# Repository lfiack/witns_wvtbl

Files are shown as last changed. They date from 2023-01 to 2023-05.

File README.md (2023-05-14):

# witns_wvtbl
Wavetable oscillator

## Make the project work
This project uses a submodule for the KiCAD library. To get it properly, use the `--recursive` option when cloning the repo :
```
git clone --recursive git@github.com:lfiack/witns_wvtbl.git
```

The firmware is developped with VSCode and the `stm32-for-vscode` plugin. There is now a plugin developped by ST, but I didn't take time to test it.

## Where to download wavetables ?
* [Free Serum Wavetables](https://www.antidoteaudio.com/free-serum-wavetables)
* [Adventurekid](https://www.adventurekid.se/akrt/waveforms/)

## TODO
* Add -12V Label

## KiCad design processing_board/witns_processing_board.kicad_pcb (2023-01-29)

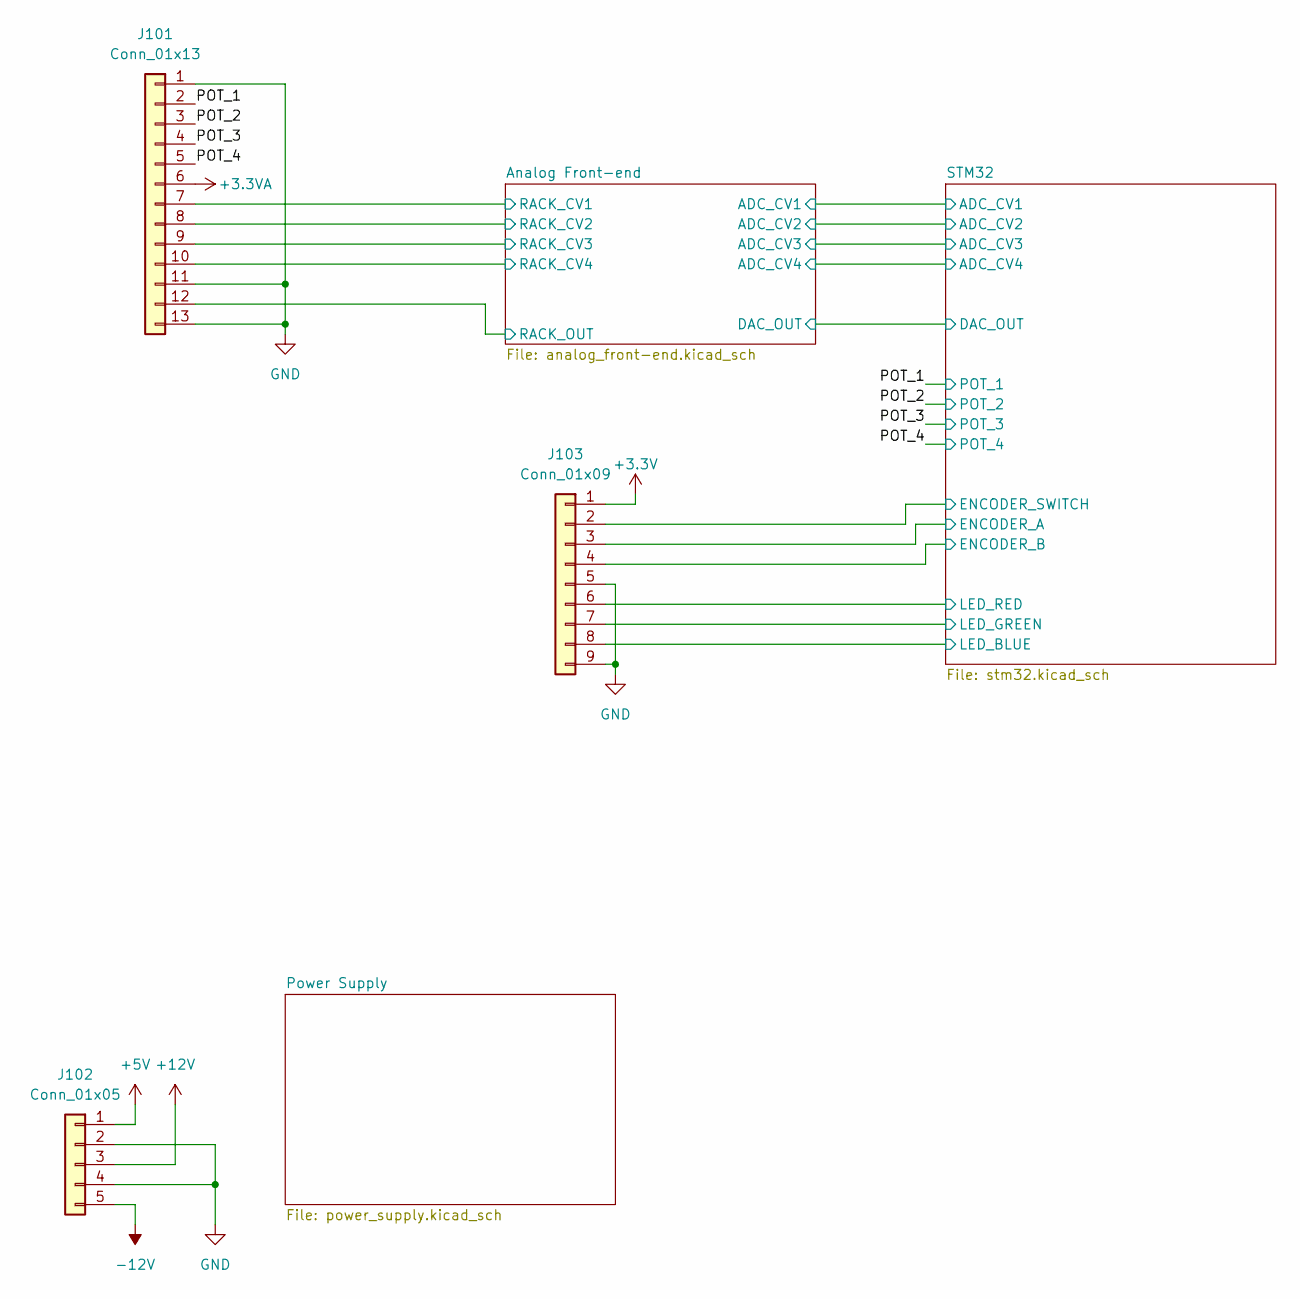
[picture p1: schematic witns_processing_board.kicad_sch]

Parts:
J101: Conn_01x13; PinHeader_1x13_P2.54mm_Vertical
J102: Conn_01x05; PinHeader_1x05_P2.54mm_Vertical
J103: Conn_01x09; PinHeader_1x09_P2.54mm_Vertical

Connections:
+3.3VA: J101.6; also elsewhere on the board
+3V3: J103.1; also elsewhere on the board
+5V: J102.1; also elsewhere on the board
+12V: J102.3; also elsewhere on the board
-12V: J102.5; also elsewhere on the board
/Analog Front-end/RACK_CV1: J101.7; also elsewhere on the board
/Analog Front-end/RACK_CV2: J101.8; also elsewhere on the board
/Analog Front-end/RACK_CV3: J101.9; also elsewhere on the board
/Analog Front-end/RACK_CV4: J101.10; also elsewhere on the board
/Analog Front-end/RACK_OUT: J101.12; also elsewhere on the board
/POT_1: J101.2; also elsewhere on the board
/POT_2: J101.3; also elsewhere on the board
/POT_3: J101.4; also elsewhere on the board
/POT_4: J101.5; also elsewhere on the board
/STM32/ENCODER_A: J103.3; also elsewhere on the board
/STM32/ENCODER_B: J103.4; also elsewhere on the board
/STM32/ENCODER_SWITCH: J103.2; also elsewhere on the board
/STM32/LED_BLUE: J103.8; also elsewhere on the board
/STM32/LED_GREEN: J103.7; also elsewhere on the board
/STM32/LED_RED: J103.6; also elsewhere on the board
GND: J101.1, J101.11, J101.13, J102.2, J102.4, J103.5, J103.9; also elsewhere on the board

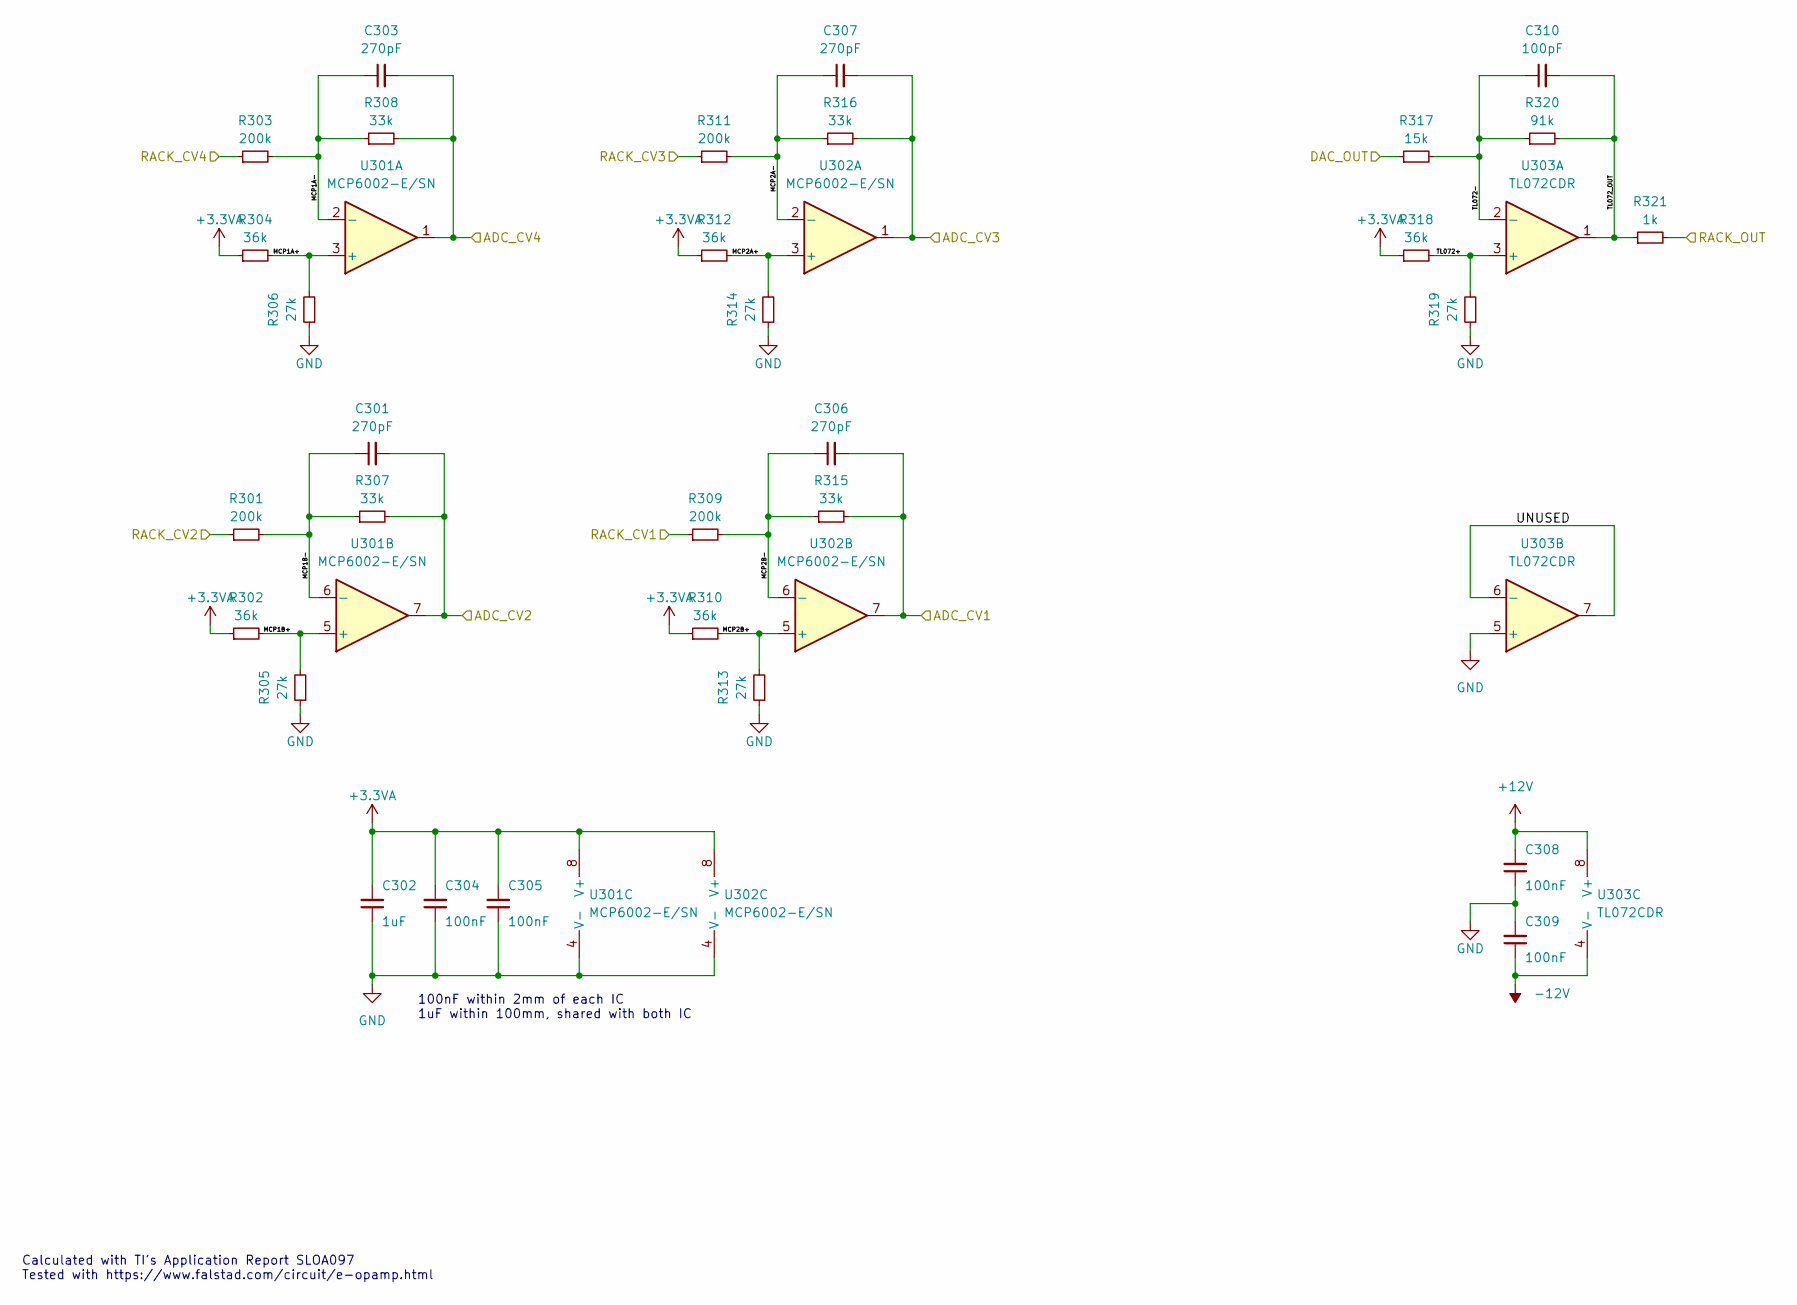
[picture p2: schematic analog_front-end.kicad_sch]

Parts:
C301, C303, C306, C307: 270pF; C_0603_1608Metric
C302: 1uF; C_0603_1608Metric
C304, C305, C308, C309: 100nF; C_0603_1608Metric
C310: 100pF; C_0603_1608Metric
R301, R303, R309, R311: 200k; R_0603_1608Metric
R302, R304, R310, R312, R318: 36k; R_0603_1608Metric
R305, R306, R313, R314, R319: 27k; R_0603_1608Metric
R307, R308, R315, R316: 33k; R_0603_1608Metric
R317: 15k; R_0603_1608Metric
R320: 91k; R_0603_1608Metric
R321: 1k; R_0603_1608Metric
U301, U302: MCP6002-E/SN; SOIC-8_3.9x4.9mm_P1.27mm
U303: TL072CDR; SOIC-8_3.9x4.9mm_P1.27mm

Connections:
+3.3VA: C302.2, C304.2, C305.2, R302.1, R304.1, R310.1, R312.1, R318.1, U301.8 (V+), U302.8 (V+); also elsewhere on the board
+12V: C308.2, U303.8 (V+); also elsewhere on the board
-12V: C309.1, U303.4 (V-); also elsewhere on the board
/Analog Front-end/ADC_CV1: C306.2, R315.2, U302.7; also elsewhere on the board
/Analog Front-end/ADC_CV2: C301.2, R307.2, U301.7; also elsewhere on the board
/Analog Front-end/ADC_CV3: C307.2, R316.2, U302.1; also elsewhere on the board
/Analog Front-end/ADC_CV4: C303.2, R308.2, U301.1; also elsewhere on the board
/Analog Front-end/DAC_OUT: R317.1; also elsewhere on the board
/Analog Front-end/MCP1A+: R304.2, R306.2, U301.3 (+)
/Analog Front-end/MCP1A-: C303.1, R303.2, R308.1, U301.2 (-)
/Analog Front-end/MCP1B+: R302.2, R305.2, U301.5 (+)
/Analog Front-end/MCP1B-: C301.1, R301.2, R307.1, U301.6 (-)
/Analog Front-end/MCP2A+: R312.2, R314.2, U302.3 (+)
/Analog Front-end/MCP2A-: C307.1, R311.2, R316.1, U302.2 (-)
/Analog Front-end/MCP2B+: R310.2, R313.2, U302.5 (+)
/Analog Front-end/MCP2B-: C306.1, R309.2, R315.1, U302.6 (-)
/Analog Front-end/RACK_CV1: R309.1; also elsewhere on the board
/Analog Front-end/RACK_CV2: R301.1; also elsewhere on the board
/Analog Front-end/RACK_CV3: R311.1; also elsewhere on the board
/Analog Front-end/RACK_CV4: R303.1; also elsewhere on the board
/Analog Front-end/RACK_OUT: R321.2; also elsewhere on the board
/Analog Front-end/TL072+: R318.2, R319.2, U303.3 (+)
/Analog Front-end/TL072-: C310.1, R317.2, R320.1, U303.2 (-)
/Analog Front-end/TL072_OUT: C310.2, R320.2, R321.1, U303.1
/Analog Front-end/UNUSED: U303.6 (-), U303.7
GND: C302.1, C304.1, C305.1, C308.1, C309.2, R305.1, R306.1, R313.1, R314.1, R319.1, U301.4 (V-), U302.4 (V-), U303.5 (+); also elsewhere on the board

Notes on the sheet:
100nF within 2mm of each IC 1uF within 100mm, shared with both IC
Calculated with TI's Application Report SLOA097 Tested with https://www.falstad.com/circuit/e-opamp.html

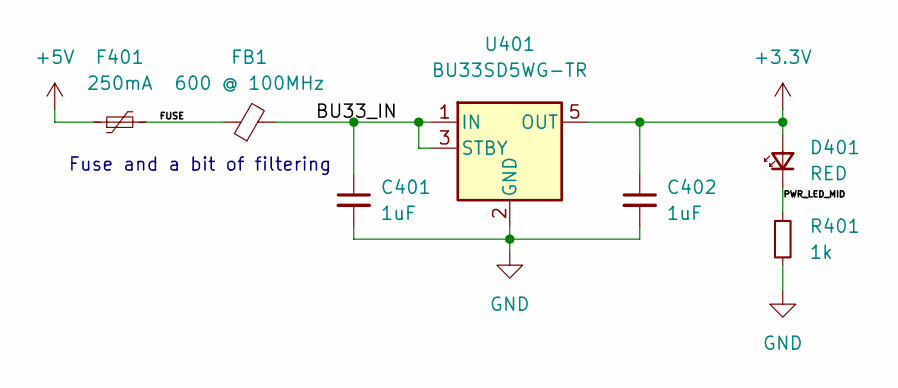
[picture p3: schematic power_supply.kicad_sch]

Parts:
C401, C402: 1uF; C_0603_1608Metric_Pad1.08x0.95mm_HandSolder
D401: RED; LED_0603_1608Metric_Pad1.05x0.95mm_HandSolder
F401: 250mA; Fuse_1206_3216Metric_Pad1.42x1.75mm_HandSolder; Farnell 2834880
FB1: 600 @ 100MHz; L_0805_2012Metric_Pad1.15x1.40mm_HandSolder; Farnell 2292460
R401: 1k; R_0603_1608Metric_Pad0.98x0.95mm_HandSolder
U401: BU33SD5WG-TR; SOT-23-5

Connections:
+3V3: C402.1, D401.2 (A), U401.5 (OUT); also elsewhere on the board
+5V: F401.1; also elsewhere on the board
/Power Supply/BU33_IN: C401.1, FB1.2, U401.1 (IN), U401.3 (STBY)
/Power Supply/FUSE: F401.2, FB1.1
/Power Supply/PWR_LED_MID: D401.1 (K), R401.1
GND: C401.2, C402.2, R401.2, U401.2 (GND); also elsewhere on the board

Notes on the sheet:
Fuse and a bit of filtering

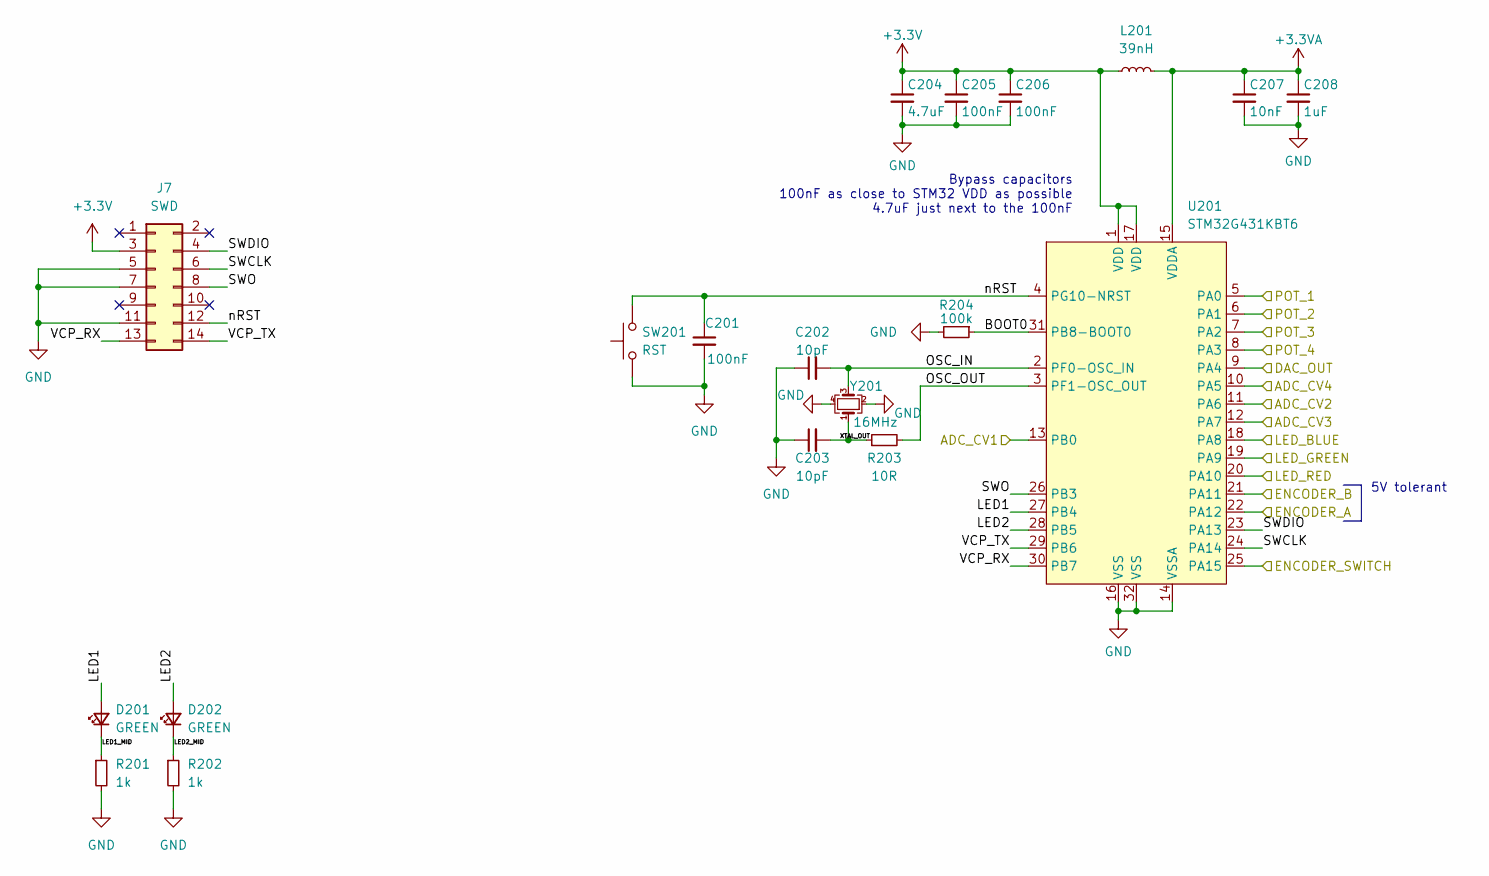
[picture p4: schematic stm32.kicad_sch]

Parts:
C201: 100nF; C_0603_1608Metric
C202, C203: 10pF; C_0603_1608Metric
C204: 4.7uF; C_0603_1608Metric_Pad1.08x0.95mm_HandSolder; Farnell 3013398
C205, C206: 100nF; C_0603_1608Metric_Pad1.08x0.95mm_HandSolder
C207: 10nF; C_0603_1608Metric_Pad1.08x0.95mm_HandSolder
C208: 1uF; C_0603_1608Metric_Pad1.08x0.95mm_HandSolder; Farnell 3013398
D201, D202: GREEN; LED_0603_1608Metric
J7: Conn_02x07_Odd_Even; PinHeader_2x07_P1.27mm_Vertical_SMD; Farnell 3226055
L201: 39nH; L_0603_1608Metric
R201, R202: 1k; R_0603_1608Metric
R203: 10R; R_0603_1608Metric
R204: 100k; R_0603_1608Metric
SW201: RST; SW_SPST_B3U-1000P; Farnell 1333652
U201: STM32G431KBT6; LQFP-32_7x7mm_P0.8mm
Y201: 16MHz; Crystal_SMD_EuroQuartz_MT-4Pin_3.2x2.5mm; Farnell 2853935

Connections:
+3.3VA: C207.1, C208.1, L201.2, U201.15 (VDDA); also elsewhere on the board
+3V3: C204.1, C205.1, C206.1, J7.3, L201.1, U201.1 (VDD), U201.17 (VDD); also elsewhere on the board
/Analog Front-end/ADC_CV1: U201.13 (PB0); also elsewhere on the board
/Analog Front-end/ADC_CV2: U201.11 (PA6); also elsewhere on the board
/Analog Front-end/ADC_CV3: U201.12 (PA7); also elsewhere on the board
/Analog Front-end/ADC_CV4: U201.10 (PA5); also elsewhere on the board
/Analog Front-end/DAC_OUT: U201.9 (PA4); also elsewhere on the board
/POT_1: U201.5 (PA0); also elsewhere on the board
/POT_2: U201.6 (PA1); also elsewhere on the board
/POT_3: U201.7 (PA2); also elsewhere on the board
/POT_4: U201.8 (PA3); also elsewhere on the board
/STM32/BOOT0: R204.1, U201.31 (PB8-BOOT0)
/STM32/ENCODER_A: U201.22 (PA12); also elsewhere on the board
/STM32/ENCODER_B: U201.21 (PA11); also elsewhere on the board
/STM32/ENCODER_SWITCH: U201.25 (PA15); also elsewhere on the board
/STM32/LED1: D201.2 (A), U201.27 (PB4)
/STM32/LED1_MID: D201.1 (K), R201.1
/STM32/LED2: D202.2 (A), U201.28 (PB5)
/STM32/LED2_MID: D202.1 (K), R202.1
/STM32/LED_BLUE: U201.18 (PA8); also elsewhere on the board
/STM32/LED_GREEN: U201.19 (PA9); also elsewhere on the board
/STM32/LED_RED: U201.20 (PA10); also elsewhere on the board
/STM32/OSC_IN: C202.2, U201.2 (PF0-OSC_IN), Y201.3
/STM32/OSC_OUT: R203.2, U201.3 (PF1-OSC_OUT)
/STM32/SWCLK: J7.6, U201.24 (PA14)
/STM32/SWDIO: J7.4, U201.23 (PA13)
/STM32/SWO: J7.8, U201.26 (PB3)
/STM32/VCP_RX: J7.13, U201.30 (PB7)
/STM32/VCP_TX: J7.14, U201.29 (PB6)
/STM32/XTAL_OUT: C203.2, R203.1, Y201.1
/STM32/nRST: C201.1, J7.12, SW201.2, U201.4 (PG10-NRST)
GND: C201.2, C202.1, C203.1, C204.2, C205.2, C206.2, C207.2, C208.2, J7.5, J7.7, J7.11, R201.2, R202.2, R204.2, SW201.1, U201.14 (VSSA), U201.16 (VSS), U201.32 (VSS), Y201.2, Y201.4; also elsewhere on the board

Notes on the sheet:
5V tolerant
Bypass capacitors 100nF as close to STM32 VDD as possible 4.7uF just next to the 100nF

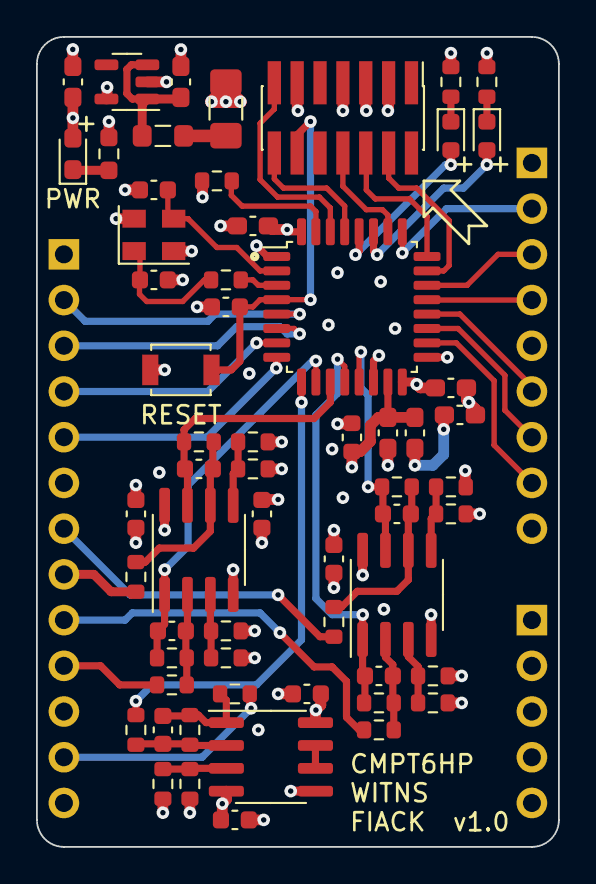
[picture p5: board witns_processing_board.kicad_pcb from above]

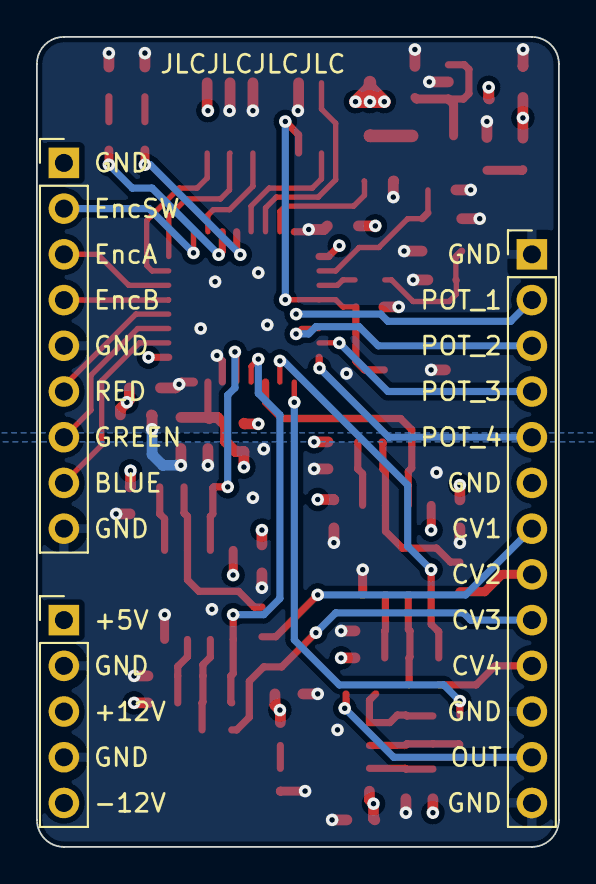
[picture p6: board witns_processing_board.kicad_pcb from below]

Board: 4 copper layers, 29.0 x 45.0 mm, 63 parts (3 on the bottom side), 55 nets.

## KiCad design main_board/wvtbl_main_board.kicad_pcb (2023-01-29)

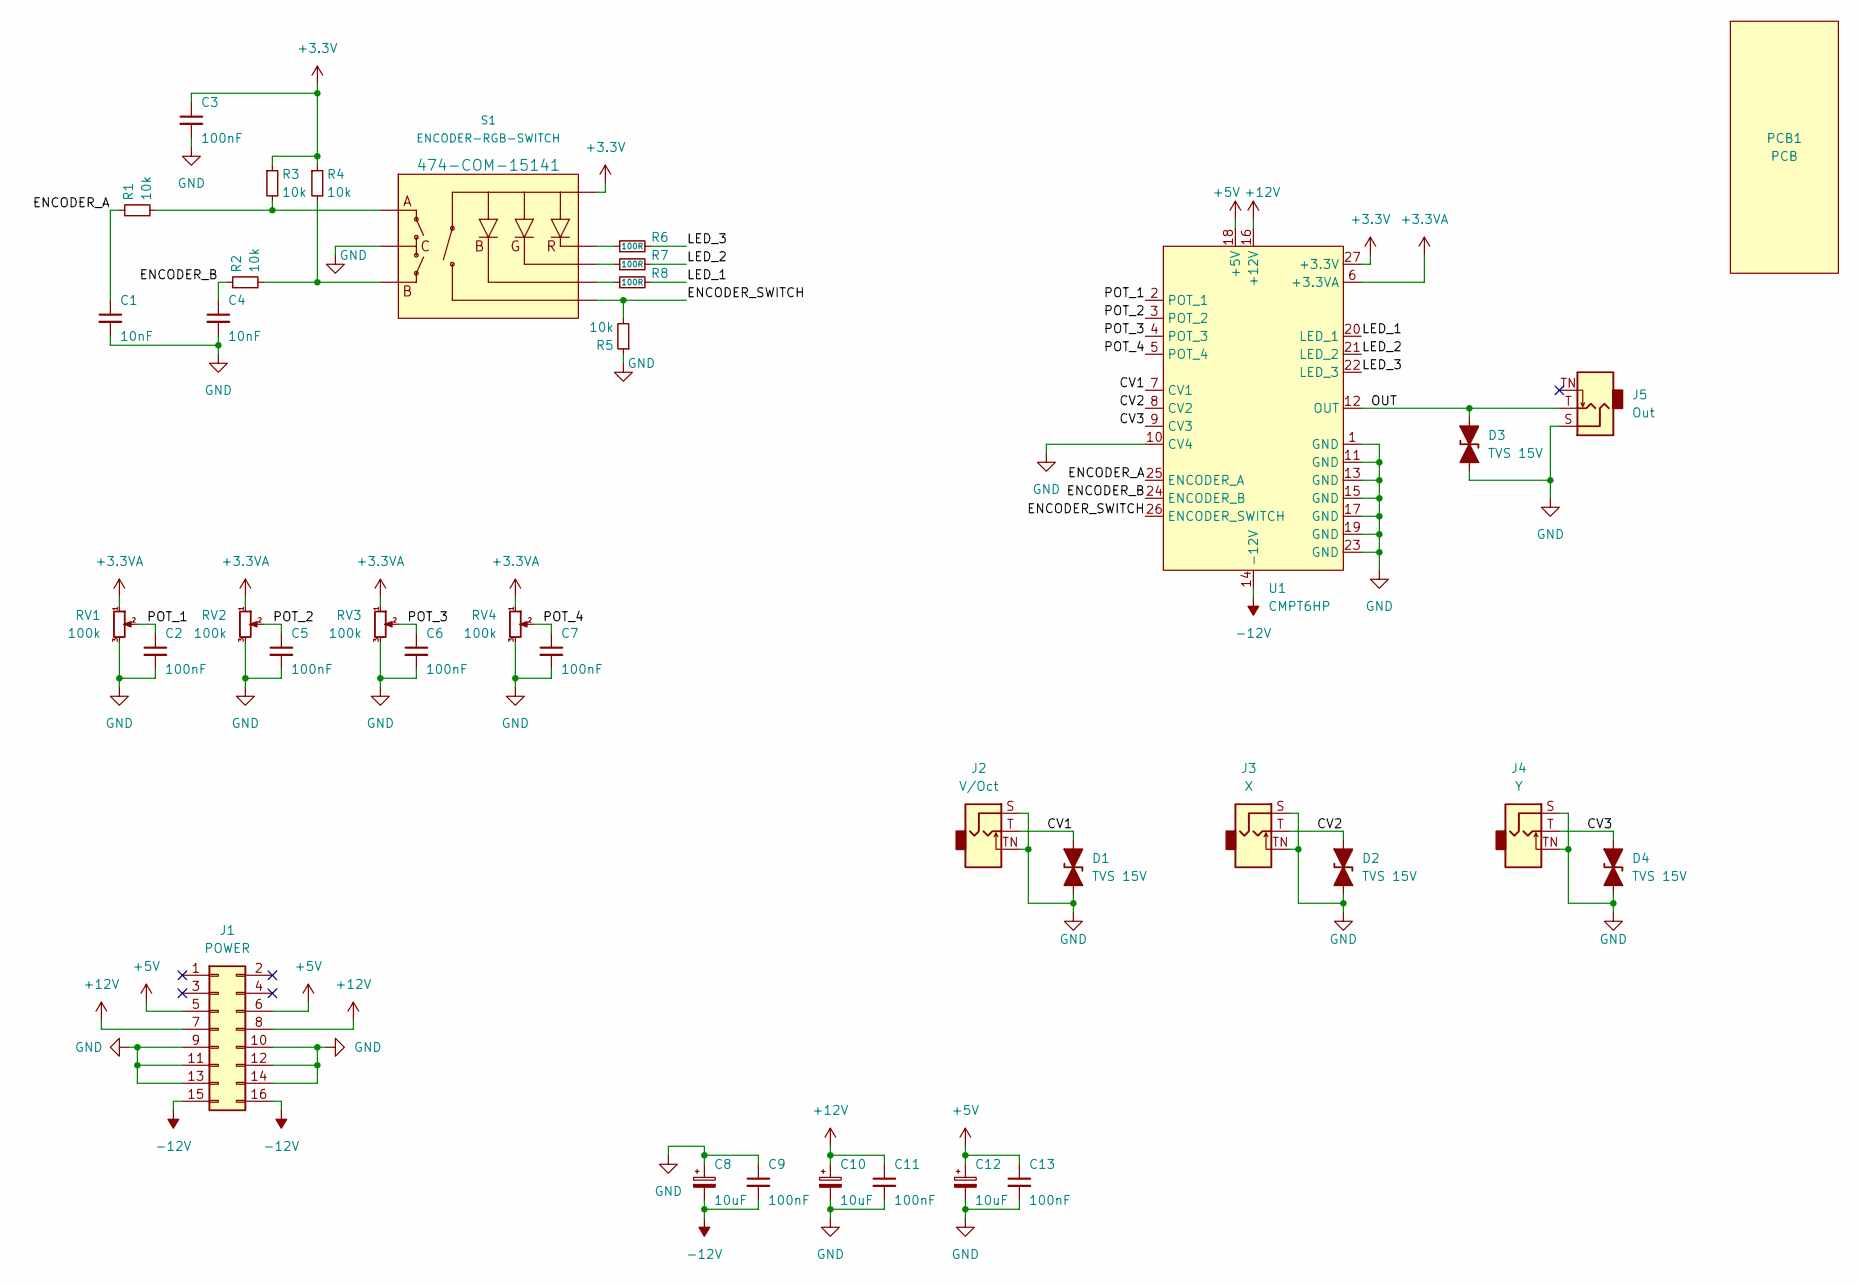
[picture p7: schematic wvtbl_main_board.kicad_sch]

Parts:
C1, C4: 10nF; C_0603_1608Metric
C2, C3, C5, C6, C7, C9, C11, C13: 100nF; C_0603_1608Metric
C8, C10, C12: 10uF; CP_Elec_4x5.4; Farnell 2611379
D1, D2, D3, D4: TVS 15V; D_SMA; Farnell 9802789
J1: POWER; PinHeader_2x08_P2.54mm_Vertical_SMD
J2: V/Oct; Jack_3.5mm_QingPu_WQP-PJ398SM_Vertical_CircularHoles
J3: X; Jack_3.5mm_QingPu_WQP-PJ398SM_Vertical_CircularHoles
J4: Y; Jack_3.5mm_QingPu_WQP-PJ398SM_Vertical_CircularHoles
J5: Out; Jack_3.5mm_QingPu_WQP-PJ398SM_Vertical_CircularHoles
PCB1: PCB; PCB_6HP
R1, R2, R3, R4, R5: 10k; R_0603_1608Metric
R6, R7, R8: 100R; R_0603_1608Metric
RV1, RV2, RV3, RV4: 100k; Potentiometer_Alpha_RD901F-40-00D_Single_Vertical
S1: ENCODER-RGB-SWITCH; ENCODER_LED_3; Mouser 474-COM-15141
U1: CMPT6HP

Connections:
+3.3V: C3.1, R3.1, R4.1, S1.5, U1.27 (+3.3V)
+3.3VA: RV1.1, RV2.1, RV3.1, RV4.1, U1.6 (+3.3VA)
+5V: C12.1, C13.1, J1.5, J1.6, U1.18 (+5V)
+12V: C10.1, C11.1, J1.7, J1.8, U1.16 (+12V)
-12V: C8.2, C9.2, J1.15, J1.16, U1.14 (-12V)
/CV1: D1.2 (A2), J2.T, U1.7 (CV1)
/CV2: D2.2 (A2), J3.T, U1.8 (CV2)
/CV3: D4.2 (A2), J4.T, U1.9 (CV3)
/ENCODER_A: C1.1, R1.1, U1.25 (ENCODER_A)
/ENCODER_B: C4.1, R2.1, U1.24 (ENCODER_B)
/ENCODER_SWITCH: R5.2, S1.3, U1.26 (ENCODER_SWITCH)
/LED_1: R8.2, U1.20 (LED_1)
/LED_2: R7.2, U1.21 (LED_2)
/LED_3: R6.2, U1.22 (LED_3)
/OUT: D3.2 (A2), J5.T, U1.12 (OUT)
/POT_1: C2.1, RV1.2, U1.2 (POT_1)
/POT_2: C5.1, RV2.2, U1.3 (POT_2)
/POT_3: C6.1, RV3.2, U1.4 (POT_3)
/POT_4: C7.1, RV4.2, U1.5 (POT_4)
GND: C1.2, C2.2, C3.2, C4.2, C5.2, C6.2, C7.2, C8.1, C9.1, C10.2, C11.2, C12.2, C13.2, D1.1 (A1), D2.1 (A1), D3.1 (A1), D4.1 (A1), J1.9, J1.10, J1.11, J1.12, J1.13, J1.14, J2.S, J2.TN, J3.S, J3.TN, J4.S, J4.TN, J5.S, R5.1, RV1.3, RV2.3, RV3.3, RV4.3, S1.C, U1.1 (GND), U1.10 (CV4), U1.11 (GND), U1.13 (GND), U1.15 (GND), U1.17 (GND), U1.19 (GND), U1.23 (GND)
unnamed: R1.2, R3.2, S1.A
unnamed: R2.2, R4.2, S1.B
unnamed: R6.1, S1.1
unnamed: R7.1, S1.2
unnamed: R8.1, S1.4

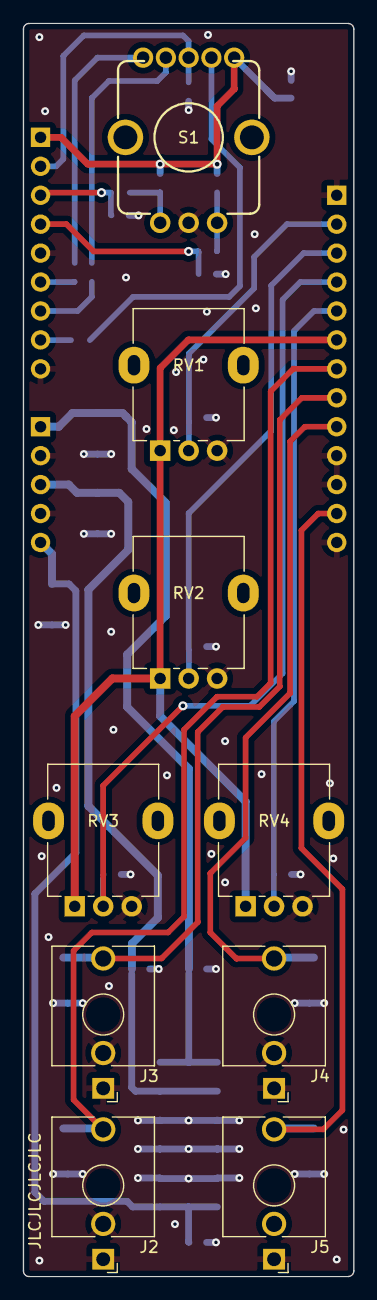
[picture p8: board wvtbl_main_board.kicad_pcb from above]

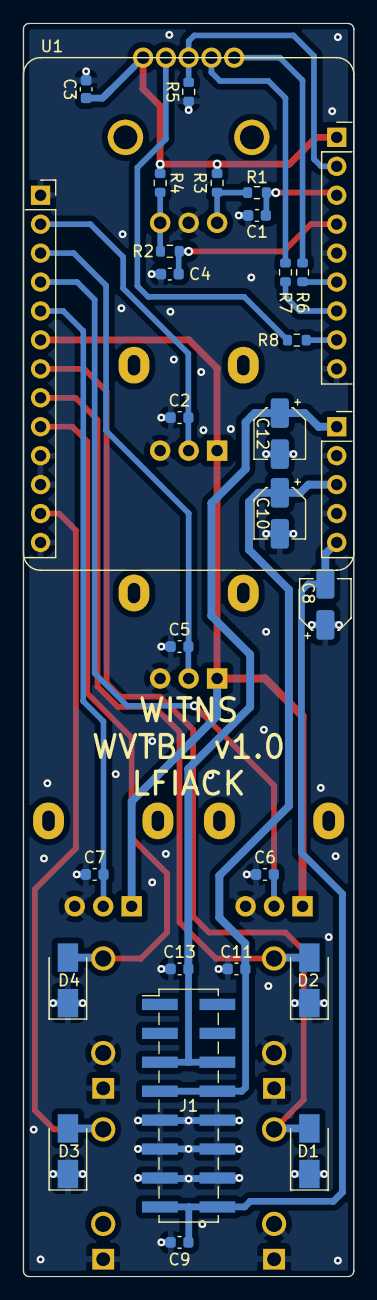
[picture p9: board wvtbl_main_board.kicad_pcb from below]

Board: 2 copper layers, 29.0 x 110.0 mm, 37 parts (27 on the bottom side), 25 nets.

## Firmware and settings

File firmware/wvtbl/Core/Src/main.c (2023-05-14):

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
/* Includes ------------------------------------------------------------------*/
#include "main.h"
#include "adc.h"
#include "dac.h"
#include "dma.h"
#include "tim.h"
#include "usart.h"
#include "gpio.h"

/* USER CODE BEGIN Includes */
#include <stdio.h>

#include "drv/led_pwm.h"
#include "drv/encoder.h"
#include "drv/analog.h"
#include "drv/eeprom.h"

#include "dsp/dsp.h"
/* USER CODE END Includes */

/* USER CODE BEGIN PTD */
typedef struct eeprom_save_struct 
{
  int32_t encoder;
  float truc;
  float machin;
} eeprom_save_t;
/* USER CODE END PTD */

/* USER CODE BEGIN PD */
#define TIM_CHANNEL_BLUE TIM_CHANNEL_1
#define TIM_CHANNEL_GREEN TIM_CHANNEL_2
#define TIM_CHANNEL_RED TIM_CHANNEL_3

//#define ADC_BUFFER_LENGTH_WORDS (ADC_BUFFER_LENGTH/2)
/* USER CODE END PD */


/* USER CODE BEGIN PV */
h_led_pwm_t h_led_red = {
  .timer_handle = &htim1,
  .timer_channel = TIM_CHANNEL_RED
};

h_led_pwm_t h_led_green = {
  .timer_handle = &htim1,
  .timer_channel = TIM_CHANNEL_GREEN
};

h_led_pwm_t h_led_blue = {
  .timer_handle = &htim1,
  .timer_channel = TIM_CHANNEL_BLUE
};

h_encoder_t h_encoder = {
  .A_GPIOx = ENCODER_A_GPIO_Port,
  .A_GPIO_pin = ENCODER_A_Pin,
  .B_GPIOx = ENCODER_B_GPIO_Port,
  .B_GPIO_pin = ENCODER_B_Pin
};

h_analog_t h_analog = {
  .adc_handles = {&hadc1, &hadc2},
  .adc_timer_handle = &htim6,
  .dac_handle = &hdac1,
  .dac_timer_handle = &htim7,
  .dac_channel = DAC_CHANNEL_1
};

h_dsp_t h_dsp = {
  .sample_frequency = 47995.48277809147f
};

static eeprom_save_t eeprom_save;

/* USER CODE END PV */

void SystemClock_Config(void);
/* USER CODE BEGIN 0 */
int _write(int file, char *ptr, int len)
{
	(void) file;

	HAL_UART_Transmit(&huart1, (uint8_t *)ptr, (uint16_t) len, HAL_MAX_DELAY);

	return len;
}

// TODO Should be placed in drv/something
void read_switch(void)
{
	static uint8_t state_SW = 0;

	if (state_SW == 0)
	{
		if (HAL_GPIO_ReadPin(ENCODER_SWITCH_GPIO_Port, ENCODER_SWITCH_Pin) == GPIO_PIN_SET)
		{
      eeprom_save.encoder = encoder_value(&h_encoder);
      printf("Saving pitch %d...\r\n", eeprom_save.encoder);
      eeprom_write((void*)&eeprom_save, sizeof(eeprom_save_t));
      printf("Pitch saved...\r\n");

			state_SW = 1;
		}
	}
	else if (state_SW == 1)
	{
		if (HAL_GPIO_ReadPin(ENCODER_SWITCH_GPIO_Port, ENCODER_SWITCH_Pin) == GPIO_PIN_RESET)
		{
			state_SW = 0;
		}
	}
}

// Called every 1 ms
void HAL_ADC_ConvCpltCallback(ADC_HandleTypeDef *hadc)
{
  if (ADC1 == hadc->Instance)
  {
    HAL_GPIO_WritePin(LED_DEBUG_GPIO_Port, LED_DEBUG_Pin, GPIO_PIN_SET);

    encoder_process(&h_encoder);
		read_switch();

    int32_t x_param = 4095 - analog_get_adc(&h_analog, ANALOG_ADC_X_PARAM_INDEX);
    int32_t y_param = 4095 - analog_get_adc(&h_analog, ANALOG_ADC_Y_PARAM_INDEX);
    int32_t pitch = 4095 - analog_get_adc(&h_analog, ANALOG_ADC_PITCH_INPUT_INDEX);  // C0 = 2V = 2376LSB ; C2 = 4V = 2814LSB
    int32_t encoder = encoder_value(&h_encoder);
    int32_t x_input = 2047 - analog_get_adc(&h_analog, ANALOG_ADC_X_INPUT_INDEX);
    int32_t y_input = 2047 - analog_get_adc(&h_analog, ANALOG_ADC_Y_INPUT_INDEX);
    int32_t x_attv = 2047 - analog_get_adc(&h_analog, ANALOG_ADC_X_ATTV_INDEX);
    int32_t y_attv = 2047 - analog_get_adc(&h_analog, ANALOG_ADC_Y_ATTV_INDEX);

    h_dsp.params[PITCH_PARAM] = encoder;

    h_dsp.params[X_PARAM] = x_param;
    h_dsp.params[Y_PARAM] = y_param;
    h_dsp.inputs[PITCH_INPUT] = pitch;
    h_dsp.inputs[X_INPUT] = (x_input * x_attv) / 1024;
    h_dsp.inputs[Y_INPUT] = (y_input * y_attv) / 1024;

    int32_t x_bright = clamp((h_dsp.inputs[X_INPUT] + h_dsp.params[X_PARAM]), 0, 4095);
    int32_t y_bright = clamp((h_dsp.inputs[Y_INPUT] + h_dsp.params[Y_PARAM]), 0, 4095);

    led_pwm_set_brightness(&h_led_red, x_bright >> 4);
//    led_pwm_set_brightness(&h_led_green, encoder + 127);
    led_pwm_set_brightness(&h_led_green, 0);
    led_pwm_set_brightness(&h_led_blue, y_bright >> 4);

    HAL_GPIO_WritePin(LED_DEBUG_GPIO_Port, LED_DEBUG_Pin, GPIO_PIN_RESET);
  }
}

void HAL_DAC_ConvHalfCpltCallbackCh1(DAC_HandleTypeDef *hdac)
{
  if (DAC1 == hdac->Instance)
  {
    HAL_GPIO_WritePin(LED_ERROR_GPIO_Port, LED_ERROR_Pin, GPIO_PIN_SET);

    dsp_process(&h_dsp, h_analog.dac_buffer, DAC_BUFFER_SIZE/2);

    HAL_GPIO_WritePin(LED_ERROR_GPIO_Port, LED_ERROR_Pin, GPIO_PIN_RESET);
  }
}

void HAL_DAC_ConvCpltCallbackCh1(DAC_HandleTypeDef *hdac)
{
  if (DAC1 == hdac->Instance)
  {
    HAL_GPIO_WritePin(LED_ERROR_GPIO_Port, LED_ERROR_Pin, GPIO_PIN_SET);

    dsp_process(&h_dsp, &h_analog.dac_buffer[DAC_BUFFER_SIZE/2], DAC_BUFFER_SIZE/2);

    HAL_GPIO_WritePin(LED_ERROR_GPIO_Port, LED_ERROR_Pin, GPIO_PIN_RESET);
  }
}

/* USER CODE END 0 */

/**
  * @brief  The application entry point.
  * @retval int
  */
int main(void)
{
  /* MCU Configuration--------------------------------------------------------*/

  /* Reset of all peripherals, Initializes the Flash interface and the Systick. */
  HAL_Init();

  /* Configure the system clock */
  SystemClock_Config();

  /* Initialize all configured peripherals */
  MX_GPIO_Init();
  MX_DMA_Init();
  MX_ADC1_Init();
  MX_ADC2_Init();
  MX_DAC1_Init();
  MX_TIM1_Init();
  MX_USART1_UART_Init();
  MX_TIM6_Init();
  MX_TIM7_Init();
  /* USER CODE BEGIN 2 */
  printf("===== WVTBL =====\r\n");

  encoder_init(&h_encoder);
  dsp_init(&h_dsp);
  
  if (0 != led_pwm_init(&h_led_red))
  {
    Error_Handler();
  }
  if (0 != led_pwm_init(&h_led_green))
  {
    Error_Handler();
  }
  if (0 != led_pwm_init(&h_led_blue))
  {
    Error_Handler();
  }

  if (0 != analog_init(&h_analog))
  {
    Error_Handler();
  }
  /* USER CODE END 2 */

  /* Infinite loop */
  /* USER CODE BEGIN WHILE */

  // TODO
  // We want to be able to calibrate the v/oct input
  // If encoder is pressed, enter calibration mode
  // Blink one color (eg. blue) while calibrating, say 1V (C2)
  // Waits second encoder press
  // We might light green LED for 1 or 2 seconds to send feedback to the user
  // Blink another color (eg. red) while calibrating, say 3V (C4)

  eeprom_read((void*)&eeprom_save, sizeof(eeprom_save_t));
  printf("Encoder value: %d\r\n", eeprom_save.encoder);
  encoder_set(&h_encoder, eeprom_save.encoder);

  while (1)
  {
#ifdef DEBUG_ENCODER
    static int32_t value = 0;

    if (h_encoder.value != value)
    {
      value = h_encoder.value;
      printf("Encoder = %ld\r\n", value);
    }
#endif // DEBUG_ENCODER

  // 2V : ADC=2380
  // 4V : ADC=2818

    float voct_sub = 2380.f;
    float voct_div = (2818.f - 2380.f) / 2.f;
    float voct = ((float)(h_dsp.inputs[PITCH_INPUT]) - voct_sub) / voct_div;
    float blblbl = (voct - (int)voct) * 1000;

    printf("ADC = %ld, V/oct = %d.%03d\r\n", h_dsp.inputs[PITCH_INPUT], (int)voct, (int)blblbl);

    HAL_Delay(1000);
    // if (h_dsp.params[PITCH_PARAM] != pitch)
    // {
    //   pitch = h_dsp.params[PITCH_PARAM];
    //   printf("Pitch = %d\r\n", (int)pitch);
    // }

		// if (counter_SW != old_counter_SW)
		// {
		// 	old_counter_SW = counter_SW;
		// 	printf("SW=%ld\r\n", counter_SW);
		// }

    // for (int it = 0 ; it < 4 ; it++)
    // {
    //   int diff = potentiometers[it] - old_potentiometers[it];
    //   if ((diff > 10) || (diff < -10))
    //   {
    //     old_potentiometers[it] = potentiometers[it];

    //     printf("Pot[%d] = %u\r\n", it, potentiometers[it]);
    //   }
    // }

    /* USER CODE END WHILE */

    /* USER CODE BEGIN 3 */
  }
  /* USER CODE END 3 */
}

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


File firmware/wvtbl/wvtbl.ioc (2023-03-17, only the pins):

Mcu.UserName=STM32G431KBTx
PA0.GPIO_Label=POT_1
PA0.Signal=ADC1_IN1
PA1.GPIO_Label=POT_2
PA1.Signal=ADC2_IN2
PA10.GPIO_Label=LED_RED
PA10.Signal=S_TIM1_CH3
PA11.GPIO_Label=ENCODER_B
PA11.Signal=GPIO_Input
PA12.GPIO_Label=ENCODER_A
PA12.Signal=GPIO_Input
PA13.Signal=SYS_JTMS-SWDIO
PA14.Signal=SYS_JTCK-SWCLK
PA15.GPIO_Label=ENCODER_SWITCH
PA15.Signal=GPIO_Input
PA2.GPIO_Label=POT_3
PA2.Signal=ADC1_IN3
PA3.GPIO_Label=POT_4
PA3.Signal=ADC1_IN4
PA4.GPIO_Label=DAC
PA4.Signal=SharedAnalog_PA4
PA5.GPIO_Label=CV4
PA5.Signal=ADC2_IN13
PA6.GPIO_Label=CV2
PA6.Signal=ADC2_IN3
PA7.GPIO_Label=CV3
PA7.Signal=ADC2_IN4
PA8.GPIO_Label=LED_BLUE
PA8.Signal=S_TIM1_CH1
PA9.GPIO_Label=LED_GREEN
PA9.Signal=S_TIM1_CH2
PB0.GPIO_Label=CV1
PB0.Signal=ADC1_IN15
PB3.Signal=SYS_JTDO-SWO
PB4.GPIO_Label=LED_ERROR
PB4.Signal=GPIO_Output
PB5.GPIO_Label=LED_DEBUG
PB5.Signal=GPIO_Output
PB6.Signal=USART1_TX
PB7.Signal=USART1_RX
PF0-OSC_IN.Signal=RCC_OSC_IN
PF1-OSC_OUT.Signal=RCC_OSC_OUT

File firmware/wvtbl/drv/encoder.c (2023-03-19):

#include "encoder.h"

void encoder_init(h_encoder_t * h_encoder)
{
    h_encoder->state = 0;
    h_encoder->value = 0;
}

void encoder_set(h_encoder_t * h_encoder, int32_t value)
{
    h_encoder->value = value;
}

void encoder_process(h_encoder_t * h_encoder)
{
    h_encoder->state = h_encoder->state << 1;
    if (HAL_GPIO_ReadPin(h_encoder->A_GPIOx, h_encoder->A_GPIO_pin) == GPIO_PIN_RESET)
    {
        h_encoder->state |= 1;
    }

    h_encoder->value += encoder_increment(h_encoder);
}

int32_t encoder_increment(h_encoder_t * h_encoder)
{
    uint32_t increment = 0;
    if (0x01 == h_encoder->state)
    {
        	if (HAL_GPIO_ReadPin(h_encoder->B_GPIOx, h_encoder->B_GPIO_pin) == GPIO_PIN_SET)
			{
				increment = 1;
			}
			else
			{
				increment = -1;
			}
    }

    return increment;
}

int32_t encoder_value(h_encoder_t * h_encoder)
{
    return h_encoder->value;
}

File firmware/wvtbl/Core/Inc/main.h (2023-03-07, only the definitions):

#define POT_1_Pin GPIO_PIN_0
#define POT_1_GPIO_Port GPIOA
#define POT_2_Pin GPIO_PIN_1
#define POT_2_GPIO_Port GPIOA
#define POT_3_Pin GPIO_PIN_2
#define POT_3_GPIO_Port GPIOA
#define POT_4_Pin GPIO_PIN_3
#define POT_4_GPIO_Port GPIOA
#define DAC_Pin GPIO_PIN_4
#define DAC_GPIO_Port GPIOA
#define CV4_Pin GPIO_PIN_5
#define CV4_GPIO_Port GPIOA
#define CV2_Pin GPIO_PIN_6
#define CV2_GPIO_Port GPIOA
#define CV3_Pin GPIO_PIN_7
#define CV3_GPIO_Port GPIOA
#define CV1_Pin GPIO_PIN_0
#define CV1_GPIO_Port GPIOB
#define LED_BLUE_Pin GPIO_PIN_8
#define LED_BLUE_GPIO_Port GPIOA
#define LED_GREEN_Pin GPIO_PIN_9
#define LED_GREEN_GPIO_Port GPIOA
#define LED_RED_Pin GPIO_PIN_10
#define LED_RED_GPIO_Port GPIOA
#define ENCODER_B_Pin GPIO_PIN_11
#define ENCODER_B_GPIO_Port GPIOA
#define ENCODER_A_Pin GPIO_PIN_12
#define ENCODER_A_GPIO_Port GPIOA
#define ENCODER_SWITCH_Pin GPIO_PIN_15
#define ENCODER_SWITCH_GPIO_Port GPIOA
#define LED_ERROR_Pin GPIO_PIN_4
#define LED_ERROR_GPIO_Port GPIOB
#define LED_DEBUG_Pin GPIO_PIN_5
#define LED_DEBUG_GPIO_Port GPIOB

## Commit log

2023-01-27 6HP Compute module
    [analog_front-end.kicad_sch, power_supply.kicad_sch, stm32.kicad_sch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]
2023-01-29 Main board PCB
    [analog_front-end.kicad_sch, power_supply.kicad_sch, stm32.kicad_sch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]
2023-01-29 fabrication files
    [witns_processing_board-B_Cu.gbr, witns_processing_board-B_Mask.gbr, witns_processing_board-B_Silkscreen.gbr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]
2023-02-27 Waveform generation
    [waveforms.ods]
2023-02-28 started ADC driver
2023-03-07 Test Encoder, LEDs, potentiometers
2023-03-08 encoder driver
2023-03-09 attempt of an analog driver
2023-03-14 led pwm driver
2023-03-17 Corrections on faceplate holes place and sizes
    [wvtbl_face_plate.kicad_pcb, wvtbl_face_plate.kicad_sch]
2023-03-17 DAC now uses DMA
2023-03-21 kicad lib

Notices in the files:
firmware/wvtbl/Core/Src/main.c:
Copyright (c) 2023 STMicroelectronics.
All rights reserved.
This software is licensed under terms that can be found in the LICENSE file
